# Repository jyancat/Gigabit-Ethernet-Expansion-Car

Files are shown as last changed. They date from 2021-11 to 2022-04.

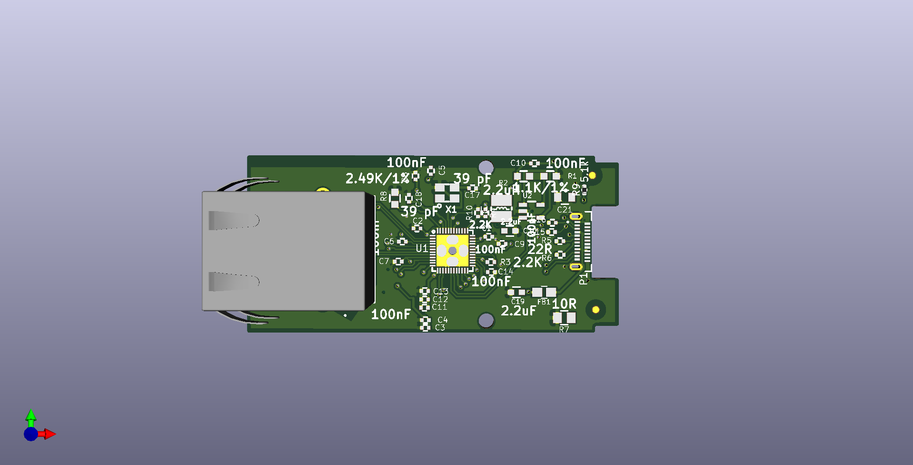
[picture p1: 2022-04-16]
Images/USB-GIGABIT_Rev_B_TOP.png

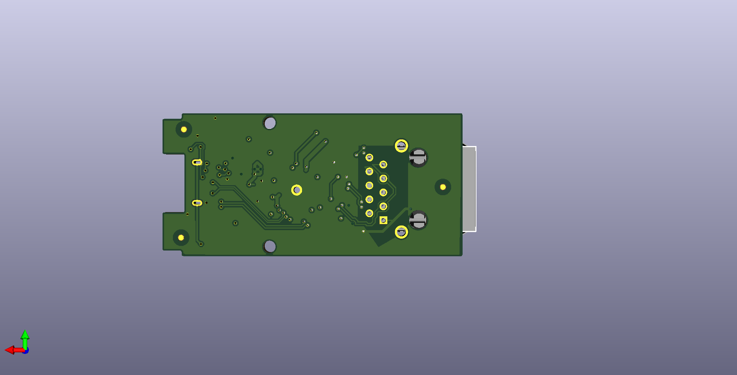
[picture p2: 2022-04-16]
Images/USB-GIGABIT_Rev_B_BOTTOM.png

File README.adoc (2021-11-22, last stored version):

= USB-C to Gigabit Ethernet for Framework Laptop

This repo is for the Gigabit Ethernet expansion card for the Framework Laptop.

Read about the Framework Laptop https://frame.work[at its home page]
and 
https://medium.com/i-tried-that/framework-laptop-saving-the-planet-one-sustainable-laptop-at-a-time-8a4cb71e54a7[at this review site].

Framework said they would build an Ethernet card, but that seems to have stalled out
as they are busy making laptops.

Read about this independent Ethernet Expansion Card project
https://community.frame.work/t/ethernet-expansion-card/8752[here].

Read how Framework is opening up the marketplace to indie vendors
(like this project, perhaps) 
https://community.frame.work/t/announcing-the-framework-marketplace/8975[here].

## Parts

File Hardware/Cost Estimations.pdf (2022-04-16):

PCBA Fabrication Cost Estimation:

OSHPark: 22USD 3 boards
seedstudio: 39.90USD 10 boars PCBWay: 25.97USD 5 boards

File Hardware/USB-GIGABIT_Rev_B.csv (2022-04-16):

Comment | Designator | Footprint | Quantity | LCPCB Part #
USB_C_Plug | P1 | GCT_USB4155-03-C_REVA | 1
100nF | C1-16 | C_0402_5MIL_DWS | 16 | C129131
39 pF | C17,C18 | C_0402_5MIL_DWS | 2 | C343867
2.2uF | C19,C20 | C_0603_5MIL_DWS | 2 | C92783
100nF/50V | C21 | C_0805_5MIL_DWS | 1 | C77082
1.1K/1% | R1-2 | R_0603_5MIL_DWS | 2 | C269415
2.2K | R3-4 | R_0402_5MIL_DWS | 2 | C227349
22R | R5-6 | R_0402_5MIL_DWS | 2 | C25152
10R | R7 | R_0805_5MIL_DWS | 1 | C137478
2.49K/1% | R8 | R_0603_5MIL_DWS | 1 | C145071
5.1k | R9 | R_0402_1005Metric | 1 | C2906948
dnp | R10 | R_0402_5MIL_DWS | 1
RTL8153VCCG | U1 | QFN48-6x6mm | 1 | C2764167
SY8089AAAC(SOT23-5) | U2 | SOT-23-5 | 1 | C141836
2.2uH | L1 | CD32 | 1 | C86423
FB0805 | FB1 | L_0805_5MIL_DWS | 1 | C1017835
SMD РЕЗ. 3225 25 Mhz 20 pf 20ppm 4p | X1 | TSX-3.2x2.5mm_GND(4) | 1 | C127893
2301994-5 | J1 | 23019945 | 1

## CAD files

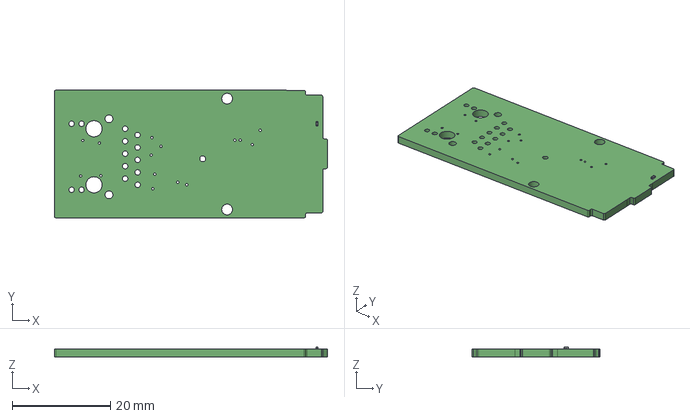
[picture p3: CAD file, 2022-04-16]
3D/USB-GIGABIT_Rev_B.step
55.6 x 26.1 x 2.00 mm

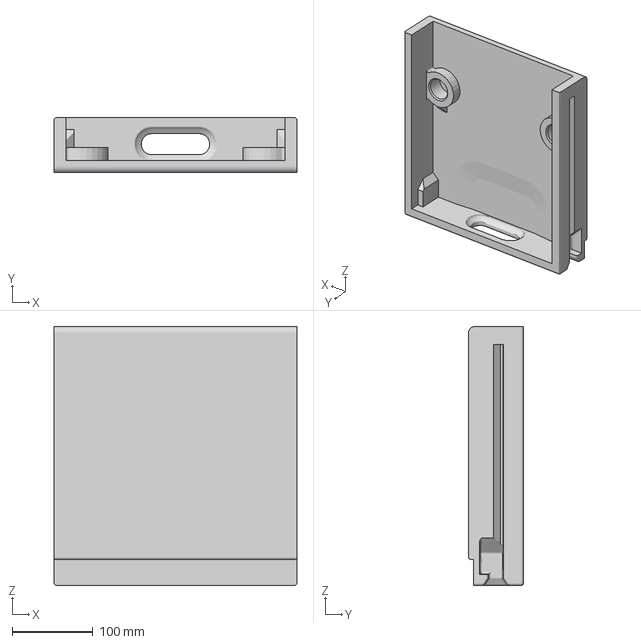
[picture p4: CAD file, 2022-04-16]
3D/MeshBody1.3mf
300.0 x 68.0 x 320.0 mm

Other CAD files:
3D/MeshBody1.stl

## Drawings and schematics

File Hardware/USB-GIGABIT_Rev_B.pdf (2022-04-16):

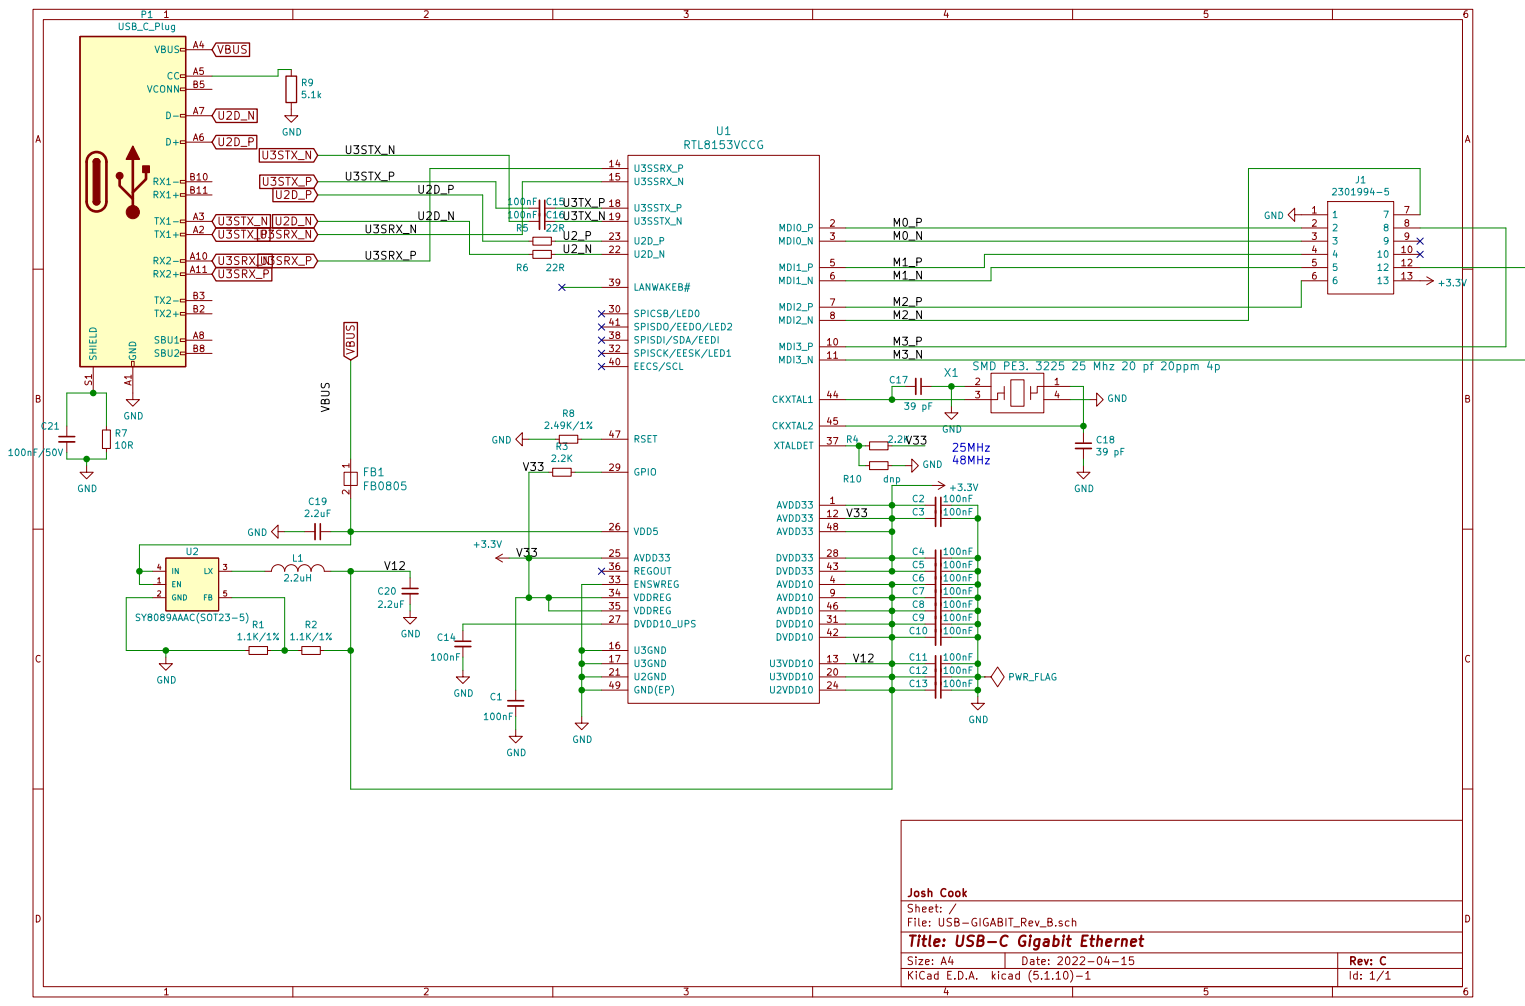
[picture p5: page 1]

U3TX_N | 39 pF GND

Id: 1/1 Title: USB-C Gigabit Ethernet

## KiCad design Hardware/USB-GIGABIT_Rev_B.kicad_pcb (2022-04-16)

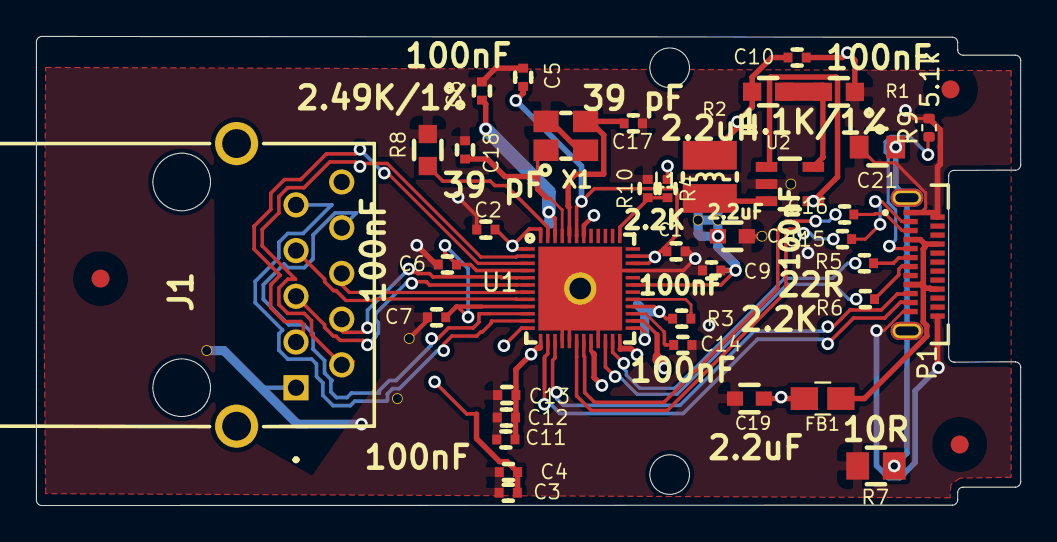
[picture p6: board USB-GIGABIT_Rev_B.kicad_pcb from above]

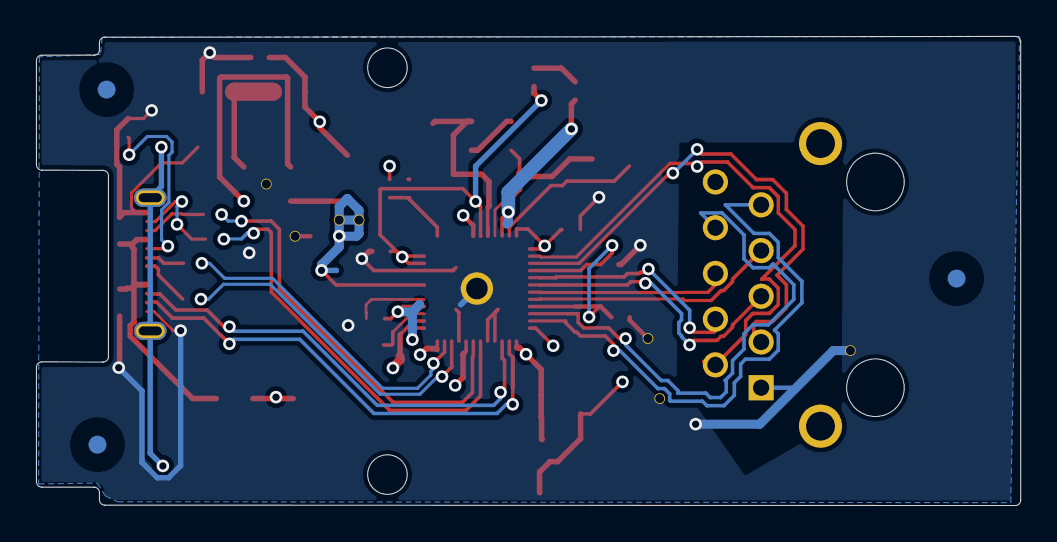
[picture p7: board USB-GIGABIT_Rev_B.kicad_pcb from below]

Board: 4 copper layers, 54.7 x 26.1 mm, 51 parts (3 on the bottom side), 33 nets.

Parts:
 : Val**; Fiducial1x3_transp
 #2: Fiducial1x3_transp
 #3,  #4,  #5,  #6,  #7: via_0.5_0.6
C1, C2, C3, C4, C5, C6, C7, C8, C9, C10, C11, C12, C13, C14, C15, C16: 100nF; C_0402_5MIL_DWS
C17, C18: 39 pF; C_0402_5MIL_DWS
C19, C20: 2.2uF; C_0603_5MIL_DWS
C21: 100nF/50V; C_0805_5MIL_DWS
FB1: FB0805; L_0805_5MIL_DWS
H1: MountingHole_2.2mm_M2
H2: MountingHole; MountingHole_2.2mm_M2
J1: 2301994-5; 23019945
L1: 2.2uH; CD32
P1: USB_C_Plug; GCT_USB4155-03-C_REVA
R1, R2: 1.1K/1%; R_0603_5MIL_DWS
R3, R4: 2.2K; R_0402_5MIL_DWS
R5, R6: 22R; R_0402_5MIL_DWS
R7: 10R; R_0805_5MIL_DWS
R8: 2.49K/1%; R_0603_5MIL_DWS
R9: 5.1k; R_0402_1005Metric
R10: dnp; R_0402_5MIL_DWS
Ref**: Val**; Fiducial1x3_transp
Ref**#2, Ref**#3, Ref**#4: Val**; Fiducial1x3_transp
U1: RTL8153VCCG; QFN48-6x6mm-OLIMEX_V2
U2: SY8089AAAC(SOT23-5); SOT-23-5
X1: SMD РЕЗ. 3225 25 Mhz 20 pf 20ppm 4p; TSX-3.2x2.5mm_GND(4)

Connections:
+3V3: C1.1, C2.2, C3.2, C4.2, C5.2, J1.13, R3.2, R4.1, U1.1, U1.12, U1.25, U1.28, U1.34, U1.35, U1.43, U1.48
/M0_N: J1.3, U1.3
/M0_P: J1.2, U1.2
/M1_N: J1.5, U1.6
/M1_P: J1.4, U1.5
/M2_N: J1.7, U1.8
/M2_P: J1.6, U1.7
/M3_N: J1.12, U1.11
/M3_P: J1.8, U1.10
/U2_N: R6.1, U1.22
/U2_P: R5.1, U1.23
/U3TX_N: C16.1, U1.19
/U3TX_P: C15.1, U1.18
/V12: #3.1, #4.1, C6.2, C7.2, C8.2, C9.2, C10.2, C11.2, C12.2, C13.2, C20.1, L1.2, R2.1, U1.4, U1.9, U1.13, U1.20, U1.24, U1.31, U1.42, U1.46
GND: #5.1, #6.1, #7.1, C1.2, C2.1, C3.1, C4.1, C5.1, C6.1, C7.1, C8.1, C9.1, C10.1, C11.1, C12.1, C13.1, C14.2, C17.1, C18.2, C19.2, C20.2, C21.2, J1.1, P1.A1, P1.A12, P1.B1, P1.B12, R1.2, R7.2, R8.2, R9.2, R10.1, U1.16, U1.17, U1.21, U1.33, U1.49, U2.2, X1.2, X1.4
unnamed: C14.1, U1.27
unnamed: C17.2, U1.44, X1.3
unnamed: C18.1, U1.45, X1.1
unnamed: C19.1, FB1.2, U1.26, U2.1, U2.4
unnamed: C21.1, P1.S1, R7.1
unnamed: L1.1, U2.3
unnamed: P1.A5, R9.1
unnamed: R1.1, R2.2, U2.5
unnamed: R3.1, U1.29
unnamed: R8.1, U1.47
unnamed: R4.2, R10.2, U1.37
U2D_N: P1.A7, R6.2
U2D_P: P1.A6, R5.2
U3SRX_N: P1.A10, U1.15
U3SRX_P: P1.A11, U1.14
U3STX_N: C16.2, P1.A3
U3STX_P: C15.2, P1.A2
VBUS: FB1.1, P1.A4, P1.A9, P1.B4, P1.B9

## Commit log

2021-10-22 Added new files.
    [USB-GIGABIT_Rev_B.kicad_pcb, USB-GIGABIT_Rev_B.sch]
2021-11-22 Updated to Newest change.
    [USB-GIGABIT_Rev_B.BOM.ods, USB-GIGABIT_Rev_B.sch]
2022-04-16 Added files using updated GCT connector and all components are on one side.
    [MeshBody1.3mf, MeshBody1.stl, USB-GIGABIT_Rev_B - Copy.csv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]
2022-04-16 removed old files
    [USB-GIGABIT_Rev_B.BOM.ods, USB-GIGABIT_Rev_B.kicad_pcb, USB-GIGABIT_Rev_B.sch]
2022-04-16 Updated Bom
    [USB-GIGABIT_Rev_B - Copy.csv, USB-GIGABIT_Rev_B.BOM.ods, USB-GIGABIT_Rev_B.csv]
